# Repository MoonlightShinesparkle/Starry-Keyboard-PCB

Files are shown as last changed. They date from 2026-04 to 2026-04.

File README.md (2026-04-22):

# Starry keyboard PCB files
A KiCad board which allows for the direct insertion or soldering of an appropriate Raspberry Pico model (the project was based in the 2W model, however a W might work) to allow the direct use of the Starry Keyboard code project. The board is based in the concept of a button matrix, allowing for the usage of 25 buttons with only 10 GPIOs from the pico, the rest being used to communicate with an EEPROM and LEDs, the project is directly based in the Moonlit Keyboard project.

# Components
The board is based in the mix of SMD and THT components, most notable SMD components being a capacitor, pull up resistors, power resistors and LEDs, meanwhile the rest of the components are THT and some were meant to be soldered with a base or with pin header sockets to allow for the easy insertion of the components and simple removal process from the board, allowing the use of the microcontroller board for other uses.

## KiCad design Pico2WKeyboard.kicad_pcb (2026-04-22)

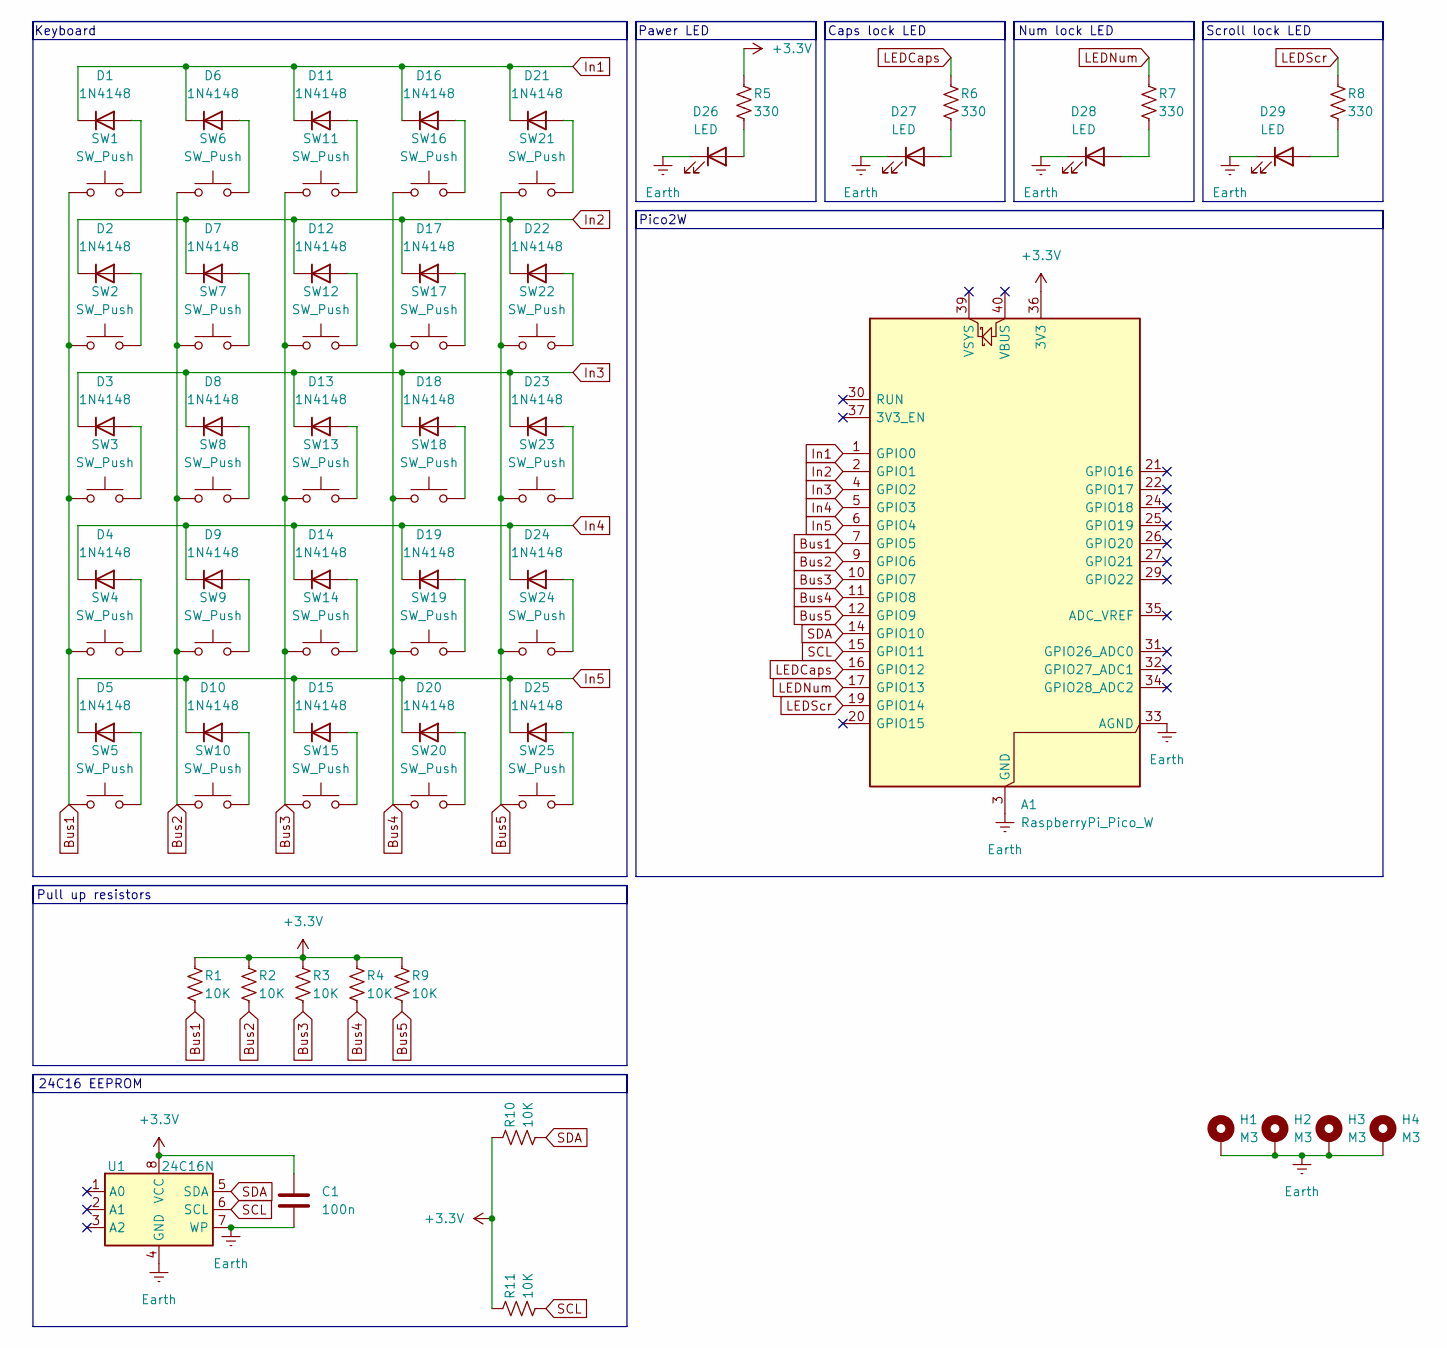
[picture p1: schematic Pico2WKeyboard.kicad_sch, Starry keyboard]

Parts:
A1: RaspberryPi_Pico_W; RaspberryPi_Pico_Common_Unspecified; LCSC C42394205
C1: 100n; C_0402_1005Metric_Pad0.74x0.62mm_HandSolder; LCSC C1525
D1, D2, D3, D4, D5, D6, D7, D8, D9, D10, D11, D12, D13, D14, D15, D16, D17, D18, D19, D20, D21, D22, D23, D24, D25: 1N4148; D_DO-35_SOD27_P7.62mm_Horizontal; LCSC C402212
D26: LED; LED_0603_1608Metric_Pad1.05x0.95mm_HandSolder; LCSC C389522
D27, D28, D29: LED; LED_0603_1608Metric_Pad1.05x0.95mm_HandSolder; LCSC C2286
H1, H2, H3, H4: M3; MountingHole_3.2mm_M3_Pad_Via
R1, R2, R3, R4, R9, R10, R11: 10K; R_0603_1608Metric_Pad0.98x0.95mm_HandSolder; LCSC C25804
R5, R6, R7, R8: 330; R_0603_1608Metric_Pad0.98x0.95mm_HandSolder; LCSC C23138
SW1, SW2, SW3, SW4, SW5, SW6, SW7, SW8, SW9, SW10, SW11, SW12, SW13, SW14, SW15, SW16, SW17, SW18, SW19, SW20, SW21, SW22, SW23, SW24, SW25: SW_Push; SW_PUSH_6mm; LCSC C393938
U1: 24C16N; DIP-8_W7.62mm_Socket; LCSC C18723551

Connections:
+3.3V: A1.36 (3V3), C1.1, R1.1, R2.1, R3.1, R4.1, R5.1, R9.1, R10.1, R11.1, U1.8 (VCC)
Bus1: A1.7 (GPIO5), R1.2, SW1.1, SW2.1, SW3.1, SW4.1, SW5.1
Bus2: A1.9 (GPIO6), R2.2, SW6.1, SW7.1, SW8.1, SW9.1, SW10.1
Bus3: A1.10 (GPIO7), R3.2, SW11.1, SW12.1, SW13.1, SW14.1, SW15.1
Bus4: A1.11 (GPIO8), R4.2, SW16.1, SW17.1, SW18.1, SW19.1, SW20.1
Bus5: A1.12 (GPIO9), R9.2, SW21.1, SW22.1, SW23.1, SW24.1, SW25.1
Earth: A1.3 (GND), A1.8 (GND), A1.13 (GND), A1.18 (GND), A1.23 (GND), A1.28 (GND), A1.33 (AGND), A1.38 (GND), C1.2, D26.1 (K), D27.1 (K), D28.1 (K), D29.1 (K), H1.1 (1_1), H2.1 (1_1), H3.1 (1_1), H4.1 (1_1), U1.4 (GND), U1.7 (WP)
In1: A1.1 (GPIO0), D1.1 (K), D6.1 (K), D11.1 (K), D16.1 (K), D21.1 (K)
In2: A1.2 (GPIO1), D2.1 (K), D7.1 (K), D12.1 (K), D17.1 (K), D22.1 (K)
In3: A1.4 (GPIO2), D3.1 (K), D8.1 (K), D13.1 (K), D18.1 (K), D23.1 (K)
In4: A1.5 (GPIO3), D4.1 (K), D9.1 (K), D14.1 (K), D19.1 (K), D24.1 (K)
In5: A1.6 (GPIO4), D5.1 (K), D10.1 (K), D15.1 (K), D20.1 (K), D25.1 (K)
LEDCaps: A1.16 (GPIO12), R6.1
LEDNum: A1.17 (GPIO13), R7.1
LEDScr: A1.19 (GPIO14), R8.1
unnamed: D1.2 (A), SW1.2
unnamed: D2.2 (A), SW2.2
unnamed: D3.2 (A), SW3.2
unnamed: D4.2 (A), SW4.2
unnamed: D5.2 (A), SW5.2
unnamed: D6.2 (A), SW6.2
unnamed: D7.2 (A), SW7.2
unnamed: D8.2 (A), SW8.2
unnamed: D9.2 (A), SW9.2
unnamed: D10.2 (A), SW10.2
unnamed: D11.2 (A), SW11.2
unnamed: D12.2 (A), SW12.2
unnamed: D13.2 (A), SW13.2
unnamed: D14.2 (A), SW14.2
unnamed: D15.2 (A), SW15.2
unnamed: D16.2 (A), SW16.2
unnamed: D17.2 (A), SW17.2
unnamed: D18.2 (A), SW18.2
unnamed: D19.2 (A), SW19.2
unnamed: D20.2 (A), SW20.2
unnamed: D21.2 (A), SW21.2
unnamed: D22.2 (A), SW22.2
unnamed: D23.2 (A), SW23.2
unnamed: D24.2 (A), SW24.2
unnamed: D25.2 (A), SW25.2
unnamed: D26.2 (A), R5.2
unnamed: D27.2 (A), R6.2
unnamed: D28.2 (A), R7.2
unnamed: D29.2 (A), R8.2
SCL: A1.15 (GPIO11), R11.2, U1.6 (SCL)
SDA: A1.14 (GPIO10), R10.2, U1.5 (SDA)

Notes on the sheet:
Num lock LED
Pico2W
24C16 EEPROM
Scroll lock LED
Keyboard
Caps lock LED
Pull up resistors
Pawer LED

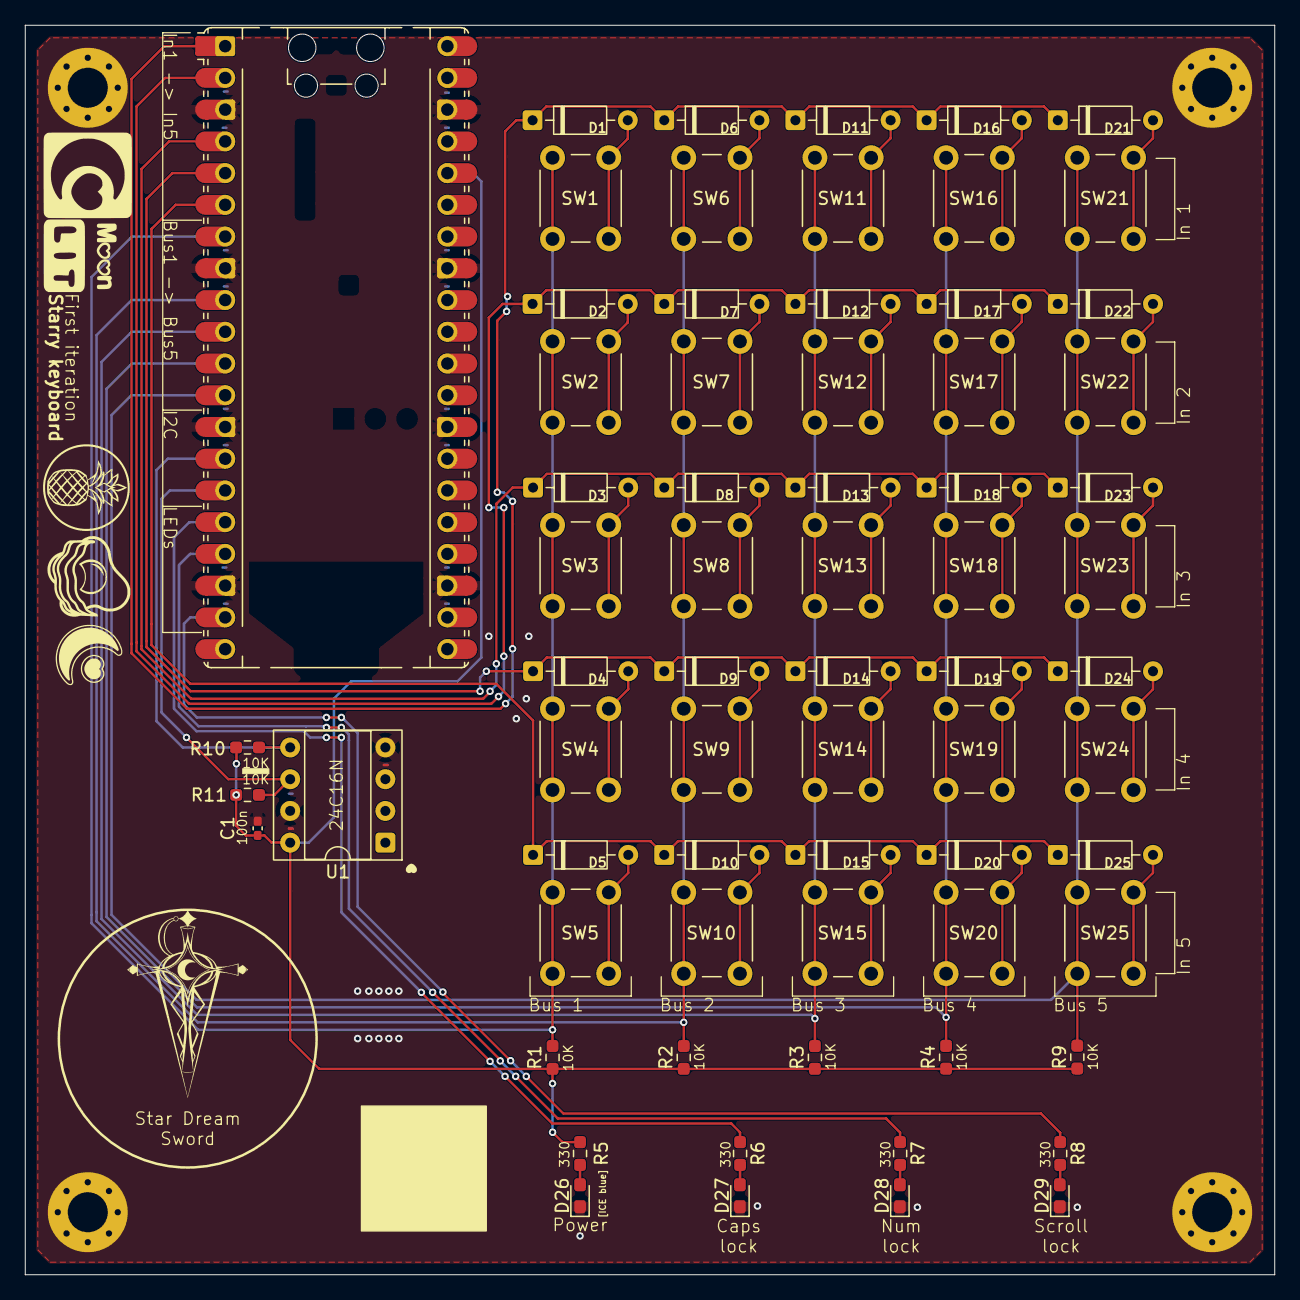
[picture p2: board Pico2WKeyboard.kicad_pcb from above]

Board: 2 copper layers, 100.0 x 100.0 mm, 72 parts (0 on the bottom side), 46 nets.

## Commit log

2026-04-22 File upload .w.
    [Pico2WKeyboard.kicad_pcb, Pico2WKeyboard.kicad_sch]
2026-04-22 Added LCSC numbers
    [Pico2WKeyboard.kicad_pcb, Pico2WKeyboard.kicad_sch]
